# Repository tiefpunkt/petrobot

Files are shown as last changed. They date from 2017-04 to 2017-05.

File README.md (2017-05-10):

# Pet Robot

A tiny Arduino-compatible robot platform. Inspired by the Pop Pet Robot.

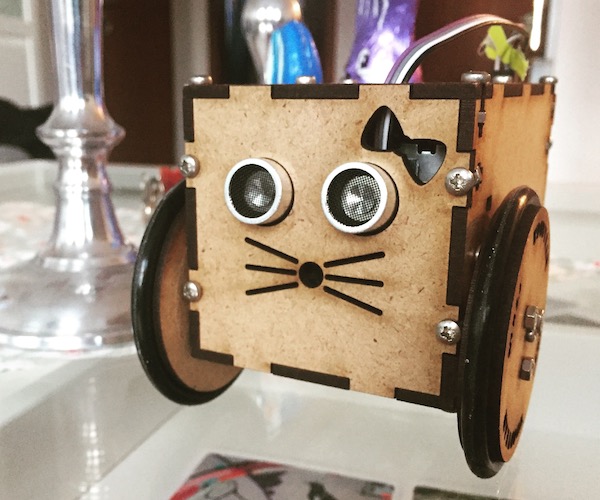
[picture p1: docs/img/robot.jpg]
Picture of the bot


## PopPet Robot
The PopPet robot was a kickstarter in 2014. It was successful, and the designs were open sourced. And then it sort of died. The website is down, the Facebook page gone, and the twitter account has gone pretty much silent.

* [Original design](https://www.thingiverse.com/thing:706375)
* [Kickstarter](https://www.kickstarter.com/projects/jaidynedwards/poppet-diy-arduino-compatible-open-hardware-robot)
* [Website](http://www.poppettherobot.com/) ([Backup on archive.org](https://web.archive.org/web/20160222195250/http://www.poppettherobot.com/))
* [Twitter](https://twitter.com/PopPetTheRobot)

## Materials
* the body and wheels are lasercut out of 3mm MDF
* motors are these quasi-standard cheap beginner robotics motors, available e.g. at [HobbyKing](https://hobbyking.com/de_de/geared-motor-w-90-deg-shaft-2pcs-bag.html)
* there's an omni-wheel caster in the back, which is probably the same as [this one](https://hobbyking.com/de_de/49x20x32mm-steel-ball-omni-wheel.html)
  * I'd like to replace it with a smaller one to also make the front wheels a bit smaller. [This one](https://hobbyking.com/de_de/50x23x25mm-steel-ball-omni-wheel.html) might be an option.
* Arduino
* Motor Shield: https://www.adafruit.com/product/81
  * The Adafruit v1 Motor Shield is not produced by Adafruit anymore, but there are clones of it available from China. They are much cheaper than any other motor shield available, but work well enough for our purpose.
  * [Documentation](https://learn.adafruit.com/adafruit-motor-shield/overview)
  * [Schematic](https://raw.githubusercontent.com/adafruit/Adafruit-Motor-Shield-for-Arduino/master/mshieldv12schem.png)
  * [More information on the shield](http://playground.arduino.cc/Main/AdafruitMotorShield)
## Firmware
### Libraries
* [Adafruit Motor Shield](https://github.com/tiefpunkt/Adafruit-Motor-Shield-library/releases/tag/1.0.1)
  * [Relevent documentation part for controlling DC motors](https://learn.adafruit.com/adafruit-motor-shield/af-dcmotor-class)
* [NewPing](https://bitbucket.org/teckel12/arduino-new-ping/downloads/)

## Notes
* Font for the wheels: [Phat Phreddy](http://www.dafont.com/de/phatt-phreddy.font?text=WOOD+YEAR)

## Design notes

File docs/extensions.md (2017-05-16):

[Home]({{ site.baseurl }}{% link index.md %}) | [Building]({{ site.baseurl }}{% link build.md %}) | [Programming]({{ site.baseurl }}{% link program.md %}) | [Extensions]({{ site.baseurl }}{% link extensions.md %})

# Modifications and extensions for your robot

## Motor speed correction
The motors in our robots are not always running at the same speed. That can be corrected in software. We've created [this example sketch](https://raw.githubusercontent.com/tiefpunkt/petrobot/master/extensions/motor_speed_adjustment/motor_speed_adjustment.ino) which you can download and flash onto your robot. In the sketch, you can find two variables, "SPEED_CORRECTION_L" and "SPEED_CORRECTION_R" to adjust the speeds of your two motors.

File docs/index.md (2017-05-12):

[Home]({{ site.baseurl }}{% link index.md %}) | [Building]({{ site.baseurl }}{% link build.md %}) | [Programming]({{ site.baseurl }}{% link program.md %}) | [Extensions]({{ site.baseurl }}{% link extensions.md %})

# Pet Robot

A tiny Arduino-based robot platform. Inspired by the Pop Pet Robot.

Picture of the bot

## PopPet Robot
The PopPet robot was a kickstarter in 2014. It was successful, and the designs were open sourced. And then it sort of died. The website is down, the Facebook page gone, and the twitter account has gone pretty much silent.

* [Original design](https://www.thingiverse.com/thing:706375)
* [Kickstarter](https://www.kickstarter.com/projects/jaidynedwards/poppet-diy-arduino-compatible-open-hardware-robot)
* [Website](http://www.poppettherobot.com/) ([Backup on archive.org](https://web.archive.org/web/20160222195250/http://www.poppettherobot.com/))
* [Twitter](https://twitter.com/PopPetTheRobot)

## Materials
* the body and wheels are lasercut out of 3mm MDF
* motors are these quasi-standard cheap beginner robotics motors, available e.g. at [HobbyKing](https://hobbyking.com/de_de/geared-motor-w-90-deg-shaft-2pcs-bag.html)
* there's an omni-wheel caster in the back, which is probably the same as [this one](https://hobbyking.com/de_de/49x20x32mm-steel-ball-omni-wheel.html)
  * I'd like to replace it with a smaller one to also make the front wheels a bit smaller. [This one](https://hobbyking.com/de_de/50x23x25mm-steel-ball-omni-wheel.html) might be an option.
* Arduino
* Motor Shield: https://www.adafruit.com/product/81
  * The Adafruit v1 Motor Shield is not produced by Adafruit anymore, but there are clones of it available from China. They are much cheaper than any other motor shield available, but work well enough for our purpose.
  * [Documentation](https://learn.adafruit.com/adafruit-motor-shield/overview)
  * [Schematic](https://raw.githubusercontent.com/adafruit/Adafruit-Motor-Shield-for-Arduino/master/mshieldv12schem.png)

## Firmware
### Libraries
* [Adafruit Motor Shield](https://github.com/tiefpunkt/Adafruit-Motor-Shield-library/releases/tag/1.0.1)
  * [Relevent documentation part for controlling DC motors](https://learn.adafruit.com/adafruit-motor-shield/af-dcmotor-class)
* [NewPing](https://bitbucket.org/teckel12/arduino-new-ping/downloads/)

## Notes
* Font for the wheels: [Phat Phreddy](http://www.dafont.com/de/phatt-phreddy.font?text=WOOD+YEAR)

## Newsletter
We finally have a newsletter. Stay updated about all that happens here at PetRobot HQ.

<!-- Begin MailChimp Signup Form -->

<div id="mc_embed_signup">
<form action="//munichmakerlab.us15.list-manage.com/subscribe/post?u=0e83a25edeba666136a8a268a&amp;id=0e4aeba960" method="post" id="mc-embedded-subscribe-form" name="mc-embedded-subscribe-form" class="validate" target="_blank" novalidate>
    <div id="mc_embed_signup_scroll">
	<label for="mce-EMAIL">Subscribe right here</label>
	<input type="email" value="" name="EMAIL" class="email" id="mce-EMAIL" placeholder="email address" required> <input type="submit" value="Subscribe" name="subscribe" id="mc-embedded-subscribe" class="button">
    <!-- real people should not fill this in and expect good things - do not remove this or risk form bot signups-->
    <div style="position: absolute; left: -5000px;" aria-hidden="true"><input type="text" name="b_0e83a25edeba666136a8a268a_0e4aeba960" tabindex="-1" value=""></div>
    
    </div>
</form>
</div>

<!-- End MailChimp Signup Form -->

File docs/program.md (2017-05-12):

[Home]({{ site.baseurl }}{% link index.md %}) | [Building]({{ site.baseurl }}{% link build.md %}) | [Programming]({{ site.baseurl }}{% link program.md %}) | [Extensions]({{ site.baseurl }}{% link extensions.md %})

# Programming your robot

## Get the Arduino IDE

You can download the Arduino IDE from [arduino.cc](https://www.arduino.cc/en/Main/Software). Grab the download for our operating system, and install the software.

## Install the libraries

The default software of your robot uses two libraries to talk to the ultrasound sensor and the motor shield. Download the ZIP files for these libraries from here:

* [Adafruit Motor Shield Library](https://github.com/tiefpunkt/Adafruit-Motor-Shield-library/releases/download/1.0.1/Adafruit-Motor-Shield-library-1.0.1.zip)
* [NewPing Library](https://bitbucket.org/teckel12/arduino-new-ping/downloads/NewPing_v1.8.zip)

Once you have downloaded the two files, start up the Arduino IDE. In the menu, go to "Sketch" -> "Include Library" -> "Add .ZIP Library..." and chose the first ZIP file you downloaded. Repeat for the second one. Now, you've installed the libraries, and can start coding.

## Get the robot software

You can download the robot's software here: [firmware.ino](https://github.com/tiefpunkt/petrobot/raw/master/firmware/firmware.ino). Download the file, and open it with the Arduino IDE. It may ask you to create a separate folder for the file, just confirm. Now, after plugging in your robot via the USB port, you should be able to press the second button on the left, and your robot should get its new software.

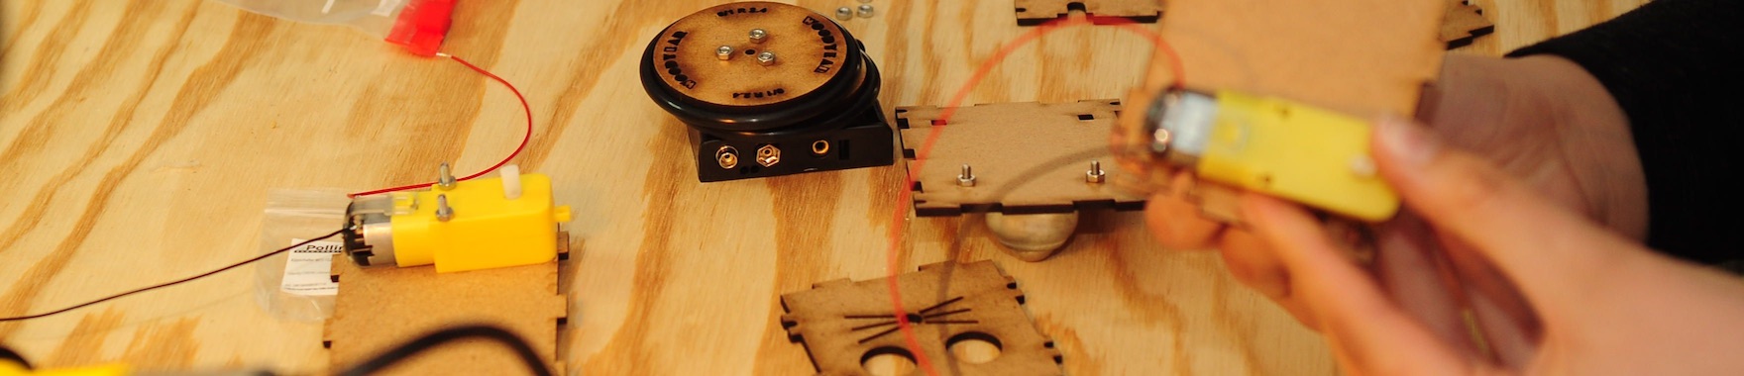
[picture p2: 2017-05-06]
docs/img/header.jpg

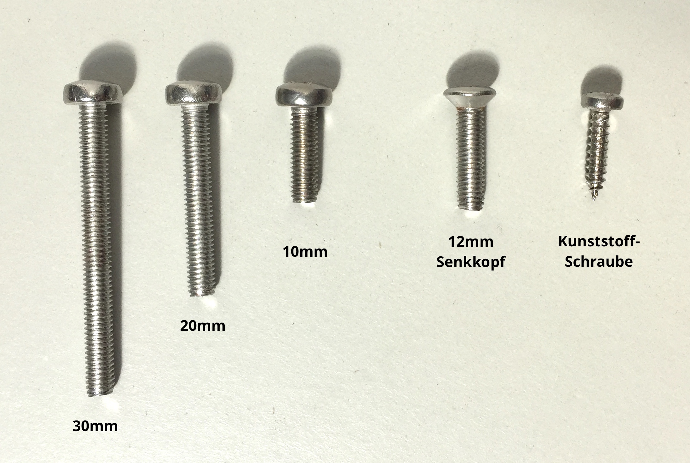
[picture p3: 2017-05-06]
docs/img/screws_de.jpg

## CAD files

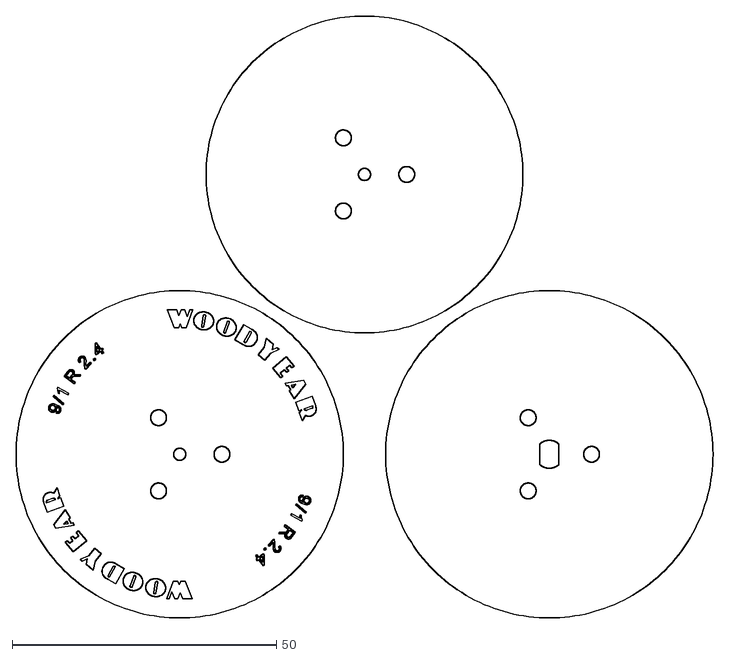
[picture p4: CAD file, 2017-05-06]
cad/wheels.dxf
132.0 x 114.0

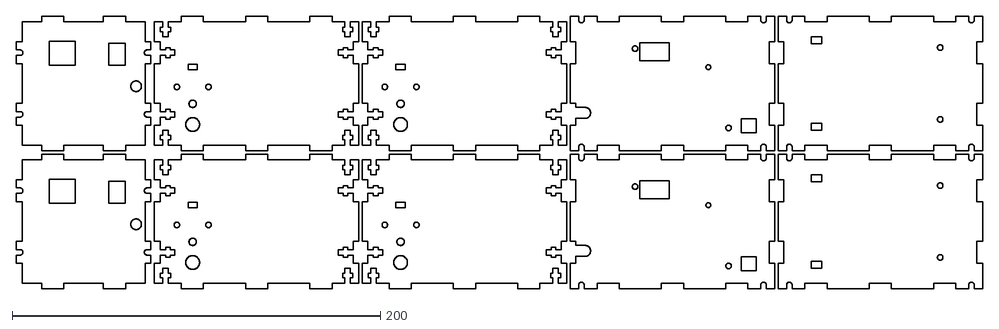
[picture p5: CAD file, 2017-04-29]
cad/petrobot.dxf
525.0 x 148.0

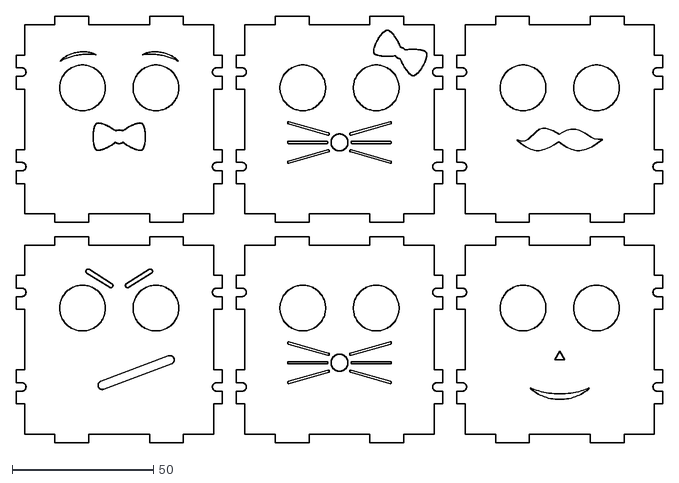
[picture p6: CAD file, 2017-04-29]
cad/faces.dxf
229.0 x 151.0

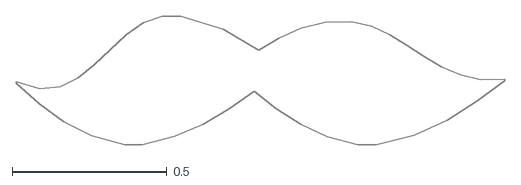
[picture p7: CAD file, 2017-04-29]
cad/mustache.dxf
1.57 x 0.414

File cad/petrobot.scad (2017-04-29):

//width_inside=60;
//height_inside=60;
//length_inside=90;

width_inside=67;
height_inside=67;
length_inside=105;


material=3;

width=width_inside+2*material;
height=height_inside+2*material;
length=length_inside+2*material;

tab = 12;
$fn=100;
module screw_hole(a) {
    rotate(a) hull() {
        translate([-0.5,0]) circle(r=1.5);
        translate([2,0]) circle(r=1.5);
    }
}

module frontback() {
    translate([material,material])
    difference() {
        union() {
            square(width_inside,height_inside);
            // Tabs
            translate([width_inside*1/4-tab/2,-material]) square([tab,material+1]);
            translate([width_inside*3/4-tab/2,-material]) square([tab,material+1]);
            translate([width_inside*1/4-tab/2,height_inside-1]) square([tab,material+1]);
            translate([width_inside*3/4-tab/2,height_inside-1]) square([tab,material+1]);
            translate([-material, height_inside*1/4-tab/2]) square([material+1,tab]);
            translate([-material, height_inside*3/4-tab/2]) square([material+1,tab]);
            translate([width_inside-1, height_inside*1/4-tab/2]) square([material+1,tab]);
            translate([width_inside-1, height_inside*3/4-tab/2]) square([material+1,tab]);
        }
        
        translate([-material/2, height_inside*1/4]) screw_hole(180);
        translate([-material/2, height_inside*3/4]) screw_hole(180);
        translate([width_inside+material/2, height_inside*1/4   ]) screw_hole(0);
        translate([width_inside+material/2, height_inside*3/4]) screw_hole(0);
    }
}

module front() {
    difference() {
        frontback();
        translate([material,material]) {
            translate([width_inside/2,height_inside*2/3]) {
                translate([-26/2,0]) circle(r=8.1);
                translate([26/2,0]) circle(r=8.1);
            }
            
            translate([width_inside/2,height_inside*1/3]) {
                translate([-6,-5]) hull() {
                    circle(r=1.5);
                    translate([24,9]) circle(r=1.5);
                }
            }
            
            translate([width_inside/2,height_inside*2/3]) {
                translate([3,8]) hull() {
                    circle(r=0.8);
                    translate([8,5]) circle(r=0.8);
                }
            }
            translate([width_inside/2,height_inside*2/3]) {
                mirror([1,0]) translate([3,8]) hull() {
                    circle(r=0.8);
                    translate([8,5]) circle(r=0.8);
                }
            }
        }
    }
}

module side() {
    translate([0,material])
    difference() {
        union() {
            square([length,height_inside]);
            translate([material+length_inside*1/6-tab/2,-material]) square([tab,material+1]);
            translate([material+length_inside*3/6-tab/2,-material]) square([tab,material+1]);
            translate([material+length_inside*5/6-tab/2,-material]) square([tab,material+1]);
            translate([material+length_inside*1/6-tab/2,height_inside-1]) square([tab,material+1]);
            translate([material+length_inside*3/6-tab/2,height_inside-1]) square([tab,material+1]);
            translate([material+length_inside*5/6-tab/2,height_inside-1]) square([tab,material+1]);
        }
        
        // Tab cutouts
        translate([-1, height_inside*1/4-tab/2]) square([material+1,tab]);
        translate([-1, height_inside*3/4-tab/2]) square([material+1,tab]);
        translate([length-material, height_inside*1/4-tab/2]) square([material+1,tab]);
        translate([length-material, height_inside*3/4-tab/2]) square([material+1,tab]);
        
        // Screw Mounts
        translate([material, height_inside*1/4]) {
            translate([-1,-1.5]) square([9,3]);
            translate([3,-2.75]) square([2.5,5.5]);
        }
        translate([material, height_inside*3/4]) {
            translate([-1,-1.5]) square([9,3]);
            translate([3,-2.75]) square([2.5,5.5]);
        }
        translate([length- material, height_inside*1/4]) mirror([1,0]) {
            translate([-1,-1.5]) square([9,3]);
            translate([3,-2.75]) square([2.5,5.5]);
        }
        translate([length- material, height_inside*3/4]) mirror([1,0]) {
            translate([-1,-1.5]) square([9,3]);
            translate([3,-2.75]) square([2.5,5.5]);
        }
        
        translate([material+3, 0]) rotate(90){
            translate([-1,-1.5]) square([9,3]);
            translate([3,-2.75]) square([2.5,5.5]);
        }
        translate([length-material-3, 0]) rotate(90){
            translate([-1,-1.5]) square([9,3]);
            translate([3,-2.75]) square([2.5,5.5]);
        }
        translate([material+3, height_inside]) rotate(270){
            translate([-1,-1.5]) square([9,3]);
            translate([3,-2.75]) square([2.5,5.5]);
        }
        translate([length-material-3, height_inside]) rotate(270){
            translate([-1,-1.5]) square([9,3]);
            translate([3,-2.75]) square([2.5,5.5]);
        }
        
        // Motor mount
        /*
        translate([material+5+7.5+7.5/2,11.2]) circle(r=7.5/2);
        translate([material+5+20.5+4/2,11.2]) circle(r=4/2);
        translate([material+5+41,11.2-5/2]) square([3,5]);
        translate([material+5+30.2+3/2,11.2-10.1+1.5]) circle(r=3/2);
        translate([material+5+30.2+3/2,11.2+10.1-1.5]) circle(r=3/2);
        */
        translate([material+6.5+7.5+7.5/2,11.2]) circle(r=7.5/2);
        translate([material+6.5+11.25,11.2-11.25+20.5+4/2]) circle(r=4/2);
        translate([material+6.5+11.25-5/2,11.2-11.25+41]) square([5,3]);
        translate([material+6.5+11.25-10.1+1.5,11.2-11.25+30.2+3/2]) circle(r=3/2);
        translate([material+6.5+11.25+10.1-1.5,11.2-11.25+30.2+3/2]) circle(r=3/2);
        
        // arduino
        /*translate([length-material-15-tab,height_inside-30-material]) square([tab,material]);
        translate([length-material-40-2*tab,height_inside-30-material]) square([tab,material]);
        */
    }
}

module topbottom() {
    difference() {
        square([length,width]);
        
        translate([-1, width_inside*1/4-tab/2+material]) square([material+1,tab]);
        translate([-1, width_inside*3/4-tab/2+material]) square([material+1,tab]);
        translate([length-material, width_inside*1/4-tab/2+material]) square([material+1,tab]);
        translate([length-material, width_inside*3/4-tab/2+material]) square([material+1,tab]);
        
        translate([material+length_inside*1/6-tab/2,-1]) square([tab,material+1]);
        translate([material+length_inside*3/6-tab/2,-1]) square([tab,material+1]);
        translate([material+length_inside*5/6-tab/2,-1]) square([tab,material+1]);
        translate([material+length_inside*1/6-tab/2,width_inside+material]) square([tab,material+1]);
        translate([material+length_inside*3/6-tab/2,width_inside+material]) square([tab,material+1]);
        translate([material+length_inside*5/6-tab/2,width_inside+material]) square([tab,material+1]);
        
        translate([material+3, material/2]) screw_hole(270);
        translate([length-material-3, material/2]) screw_hole(270);
        translate([material+3, width-material/2]) screw_hole(90);
        translate([length-material-3, width-material/2]) screw_hole(90);
    }
}


module bottom() {
    difference() { 
        topbottom();
        
        translate([material+6.5+11.25-5.5/2,material+8]) square([5.5,4]);
        translate([material+6.5+11.25-5.5/2,material+width_inside-8-4]) square([5.5,4]);
        translate([material+length_inside-20,width/2-39/2]) circle(r=1.5);
        translate([material+length_inside-20,width/2+39/2]) circle(r=1.5);
    }
}
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

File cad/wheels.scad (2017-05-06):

$fn=200;

module curved_text(string, r, size, font, angle) {
    for (a =[0:len(string)]) {
        rotate(a*angle*-1) translate([0,r]) text(string[a], size=size, font=font, halign="center");
    }
}

difference() {
    circle(r=60/2+1);
    circle(r=1.15);
    translate([8,0]) circle(r=1.5);
    rotate(120) translate([8,0]) circle(r=1.5);
    rotate(240) translate([8,0]) circle(r=1.5);
    
    //translate([-16,19]) text("WOODYEAR", size=3, font="PhattPhreddy", spacing=1.2);
    curved_text("WOODYEAR", size=3, font="PhattPhreddy", r=24, angle=10);
    rotate(180) curved_text("WOODYEAR", size=3, font="PhattPhreddy", r=24, angle=10);
    rotate(70) curved_text("9/1 R 2.4", size=2.4, font="Arial", r=24, angle=4);
    rotate(180+70) curved_text("9/1 R 2.4", size=2.4, font="Arial", r=24, angle=4);
    //rotate(180) translate([-16,19]) text("WOODYEAR", size=3, font="PhattPhreddy", spacing=1.2);
}

translate([70,0]) difference() {
    circle(r=60/2+1);
    difference() {
        circle(r=5.3/2);
        translate([3.6/2,-5]) square([10,10]);
        translate([-10-3.6/2,-5]) square([10,10]);
        
    }
    translate([8,0]) circle(r=1.5);
    rotate(120) translate([8,0]) circle(r=1.5);
    rotate(240) translate([8,0]) circle(r=1.5);
    
    //translate([-16,19]) text("WOODYEAR", size=3, font="PhattPhreddy", spacing=1.2);
    //rotate(180) translate([-16,19]) text("WOODYEAR", size=3, font="PhattPhreddy", spacing=1.2);
}

translate([35,53]) difference() {
    circle(r=60/2);
    /*difference() {
        circle(r=5.3/2);
        translate([3.6/2,-5]) square([10,10]);
        translate([-10-3.6/2,-5]) square([10,10]);
        
    }*/
    circle(r=1.15);
    translate([8,0]) circle(r=1.5);
    rotate(120) translate([8,0]) circle(r=1.5);
    rotate(240) translate([8,0]) circle(r=1.5);
}

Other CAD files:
cad/faces.scad

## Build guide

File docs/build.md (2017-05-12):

[Home]({{ site.baseurl }}{% link index.md %}) | [Building]({{ site.baseurl }}{% link build.md %}) | [Programming]({{ site.baseurl }}{% link program.md %}) | [Extensions]({{ site.baseurl }}{% link extensions.md %})

# Building your robot

## 1. Parts

Check your parts..

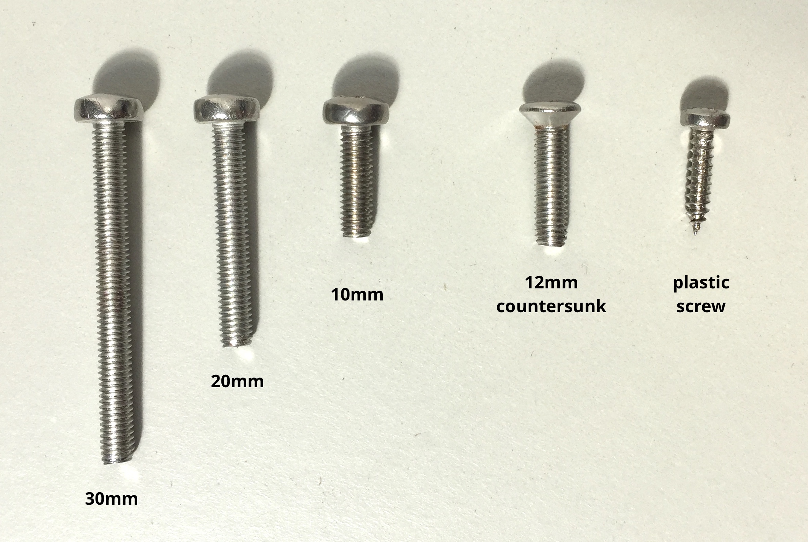
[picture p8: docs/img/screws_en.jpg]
Different screws in the kit


You should have the follwing screws:
* M3 x 30mm (4x)
* M3 x 20mm (2x)
* M3 x 10mm (18x)
* M3 x 12mm countersunk (6x)
* plastic screw (2x)

## 2. Soldering

Before we put the robot together, you need to solder a some wires to the motors, as well as the power switch of your robot.

### Motors

There are two copper terminals on each motor. Solder a red wire to the right terminal, and a black wire to the left terminal. Repeat for the other motor.

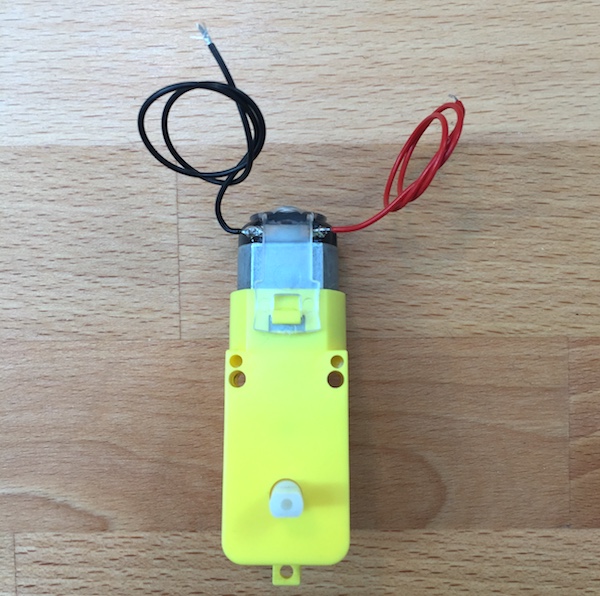
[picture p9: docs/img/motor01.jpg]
Motor with wires


### Power Switch

The power switch is connected between the positive side of the battery and the motor shield. So you need to solder the red (positive) wire of the battery connector to the switch, and an additional red wire as well. The switch has three tabs, you need to solder one wire to the middle tab, and the other wire to one of the outside tabs.

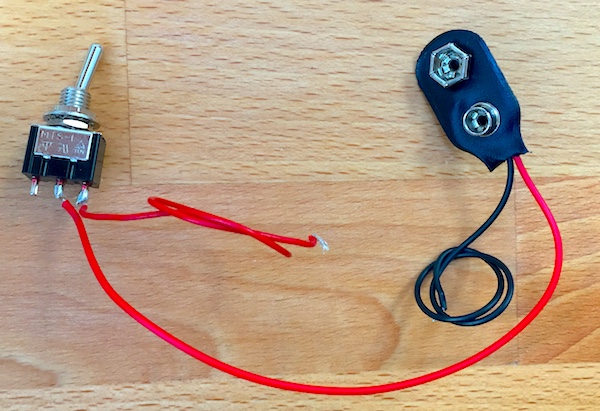
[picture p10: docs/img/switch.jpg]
Power switch with wires attached


## 3. Putting everything together

### Motors

Mount the motors to their panels. There are two side panels, one for each motor. Since you can mount the motor from either side, make sure mount one motor to one side of the first panel, and the second motor to the other side of the other panel (as in the picture below).

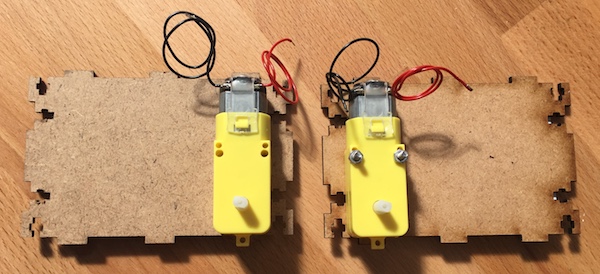
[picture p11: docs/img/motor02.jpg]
Motors on their side panels


Use the 30mm bolts to fasten the motors to the panels, having the heads of the bolts on the outside of the panel, and the nuts on the motor, as shown below.

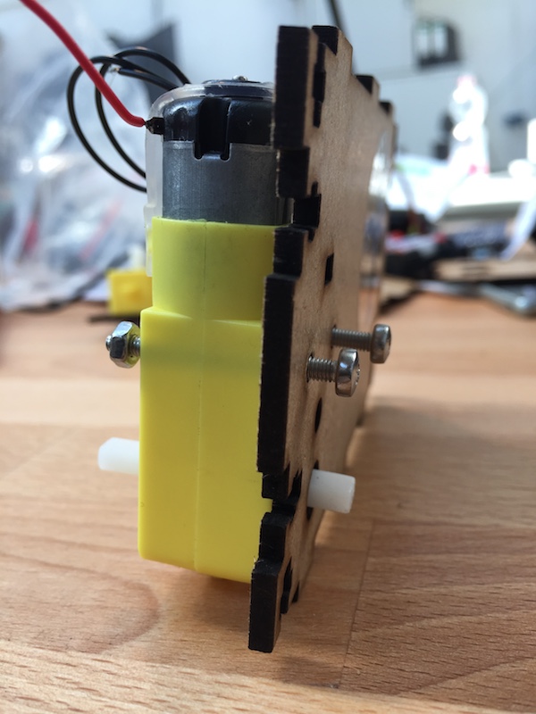
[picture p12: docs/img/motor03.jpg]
Motor bolts


### Bottom ball caster

Take the bottom plate, put the ball caster onto the matching two holes, and screw it together with 2 M3x10mm screws and nuts.

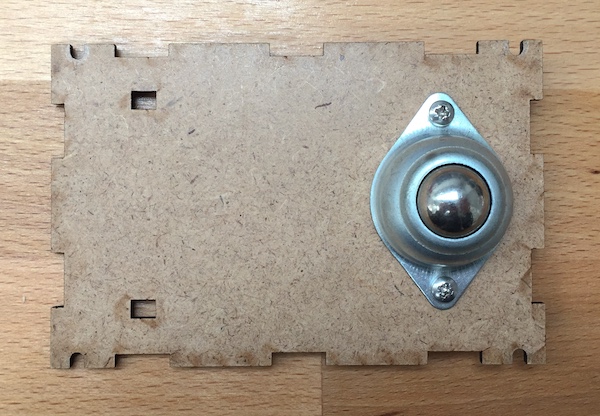
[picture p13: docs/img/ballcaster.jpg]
Ballcaster mounted to the bottoms plate


### Ultrasound distance sensor

The ultrasound distance sensor is going to be connected with the 4-pin cable. Since you won't be able to see the connector when plugging the other side of the cable in, take some tape and label the other side of the cable with the names of the pins on the sensor (as shown below). On some sensors, the labels are on the front of the sensor instead.

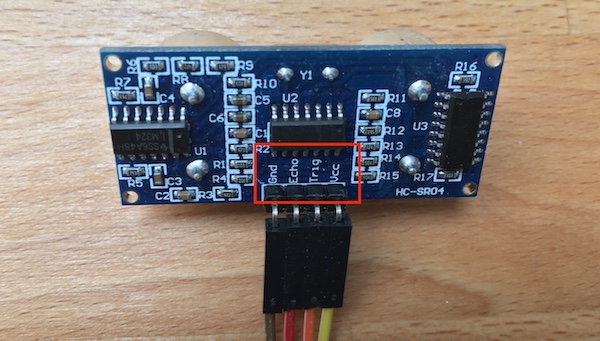
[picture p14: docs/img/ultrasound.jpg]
Ultrasound sensor with pin labels


Next, take the sensor and put it through the eye cutouts of the face plate. The cables should point downwards.

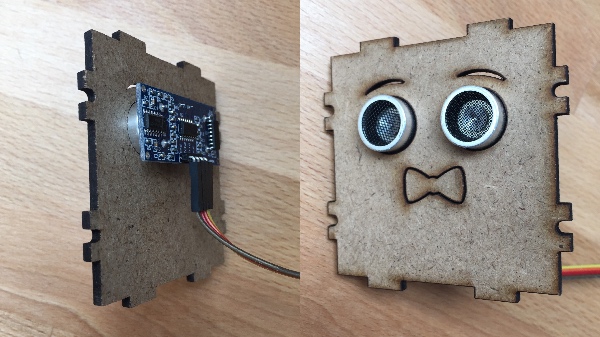
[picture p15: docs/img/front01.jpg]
Ultrasound sensor mounted in the front plate


### The power switch

The power switch goes into the back plate, through the circular hole. With the two square holes on the top, the switch should be on the right side of the back panel. Mount it so the swicht goes up and down, not left to right, otherwise the plate don't fit on the rest of the robot.

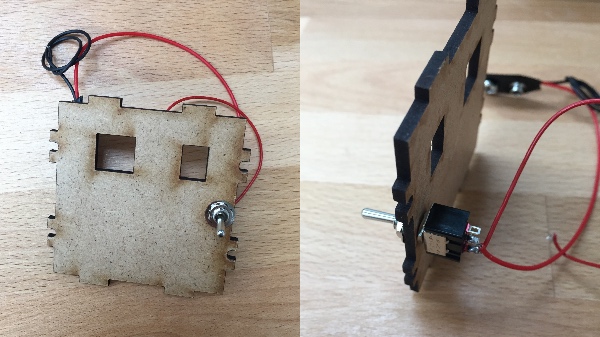
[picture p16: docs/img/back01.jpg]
Power switch in back plate


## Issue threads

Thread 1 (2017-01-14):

Electronics?

tiefpunkt, 2017-01-14:
What should be the robot's brain?

Some options:
* Arduino Uno + motor shield
  * [L293D motor shield](https://www.aliexpress.com/item/1pcs-L293D-Motor-Drive-Shield-dual-for-arduino-Duemilanove-Motor-drive-expansion-board/32659866494.html)
* [NodeMCU with motor shield](https://www.aliexpress.com/item/NodeMCU-Development-Kit-NodeMCU-Motor-Shield-esp-wifi-esp8266-esp-12e-esp-12e-kit-diy-rc/32445659965.html)
* WeMos Mini with its [I2C motor shield](https://www.wemos.cc/product/motor-shield.html)
* [DAGU Arduino compatible motor controller](http://www.dagurobot.com/goods.php?id=142) (used on the original Pop Pet)

tiefpunkt, 2017-01-16:
Documentation on how to use the L293D motor shield is right here: https://learn.adafruit.com/adafruit-motor-shield/overview

tiefpunkt, 2017-01-18:
Another source for the DAGU board: https://nodna.de/Dagu-Arduino-AVR-board-mit-H-Bruecke

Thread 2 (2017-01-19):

Motors

tiefpunkt, 2017-01-19:
Where to buy motors?
* https://nodna.de/200-1-Plastic-Gearmotor-90-Output
* https://hobbyking.com/de_de/geared-motor-w-90-deg-shaft-2pcs-bag.html
* AliExpress?

tiefpunkt, 2017-05-08:
Went with aliexpress, with motors that look identical to the hobby king versions

Closed 2017-05-08.

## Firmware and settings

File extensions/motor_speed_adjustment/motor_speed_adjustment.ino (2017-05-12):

#include "AFMotor.h"

AF_DCMotor motor_l(1);
AF_DCMotor motor_r(2);

#include <NewPing.h>

#define TRIGGER_PIN  10  // Arduino pin tied to trigger pin on the ultrasonic sensor.
#define ECHO_PIN     9  // Arduino pin tied to echo pin on the ultrasonic sensor.

NewPing sonar(TRIGGER_PIN, ECHO_PIN, 100); // NewPing setup of pins and maximum distance.

#define STOP_DISTANCE 15


#define SPEED_MIN    40
#define SPEED_STEPS  20
#define SPEED_FINAL 160

#define SPEED_TURNING 100

#define SPEED_CORRECTION_L 1.0
#define SPEED_CORRECTION_R 1.0

int speed = 0;
int distance, d1;

void setup()
{
  Serial.begin(9600);
}


void setSpeed(int s) {
  int speed_l = (int)(s*SPEED_CORRECTION_L);
  int speed_r = (int)(s*SPEED_CORRECTION_R);
  motor_l.setSpeed(speed_l);
  motor_r.setSpeed(speed_r);
  Serial.print("Speed L: ");
  Serial.println(speed_l);
  Serial.print("Speed R: ");
  Serial.println(speed_r);
}


void loop()
{
  distance = sonar.ping_cm();
  Serial.print("Distance: ");
  Serial.println(distance);
/*
  if (distance > 0 && distance<=STOP_DISTANCE) {
    delay(30);
    distance += sonar.ping_cm();
    distance /= 2;
  }
*/

  if (distance > 0 && distance <= STOP_DISTANCE) {
    setSpeed(SPEED_TURNING);
    motor_l.run(RELEASE);
    motor_r.run(RELEASE);
    speed = 0;
    motor_l.run(BACKWARD);
    motor_r.run(BACKWARD);
    delay(200);
    motor_l.run(RELEASE);
    motor_r.run(RELEASE);
    delay(200);
    motor_l.run(FORWARD);
    motor_r.run(BACKWARD);
    delay(700);
    motor_l.run(RELEASE);
    motor_r.run(RELEASE);
  } else {
    motor_l.run(FORWARD);
    motor_r.run(FORWARD);
    if (speed < SPEED_MIN) {
      speed = SPEED_MIN;
    } else if (speed < SPEED_FINAL) {
      speed += SPEED_STEPS;
    }
    setSpeed(speed);
  }

  delay(200);
}
// END FILE

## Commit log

2017-01-14 details on materials
2017-01-16 Arduino holder and fixes
    * Added internal holder for Arduino and motor shield, incl. cutouts in the back and top panel
    * moved screws of bottom and top plate a bit further out towards the edges, but they still collide with the motor :-/
    * adjusted holes for ultrasound sensor
    [petrobot.dxf, petrobot.scad]
2017-01-20 new wheels, bigger chassis to accomodate battery pack
    [petrobot.dxf, petrobot.scad, wheels.dxf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]
2017-03-10 cad things
    [petrobot.dxf, petrobot.scad]
2017-03-10 firmware for other motor shield
2017-03-10 Add links to motor shield docs to README
2017-04-29 smaller wheels, new motor shield, many faces
    [faces.dxf, faces.scad, mustache.dxf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]
2017-05-06 better wheels, documentation
    [wheels.dxf, wheels.scad]
2017-05-12 extension for indiviuial motor speed correntions
2017-05-16 fixed link to motor speed correction sketch
